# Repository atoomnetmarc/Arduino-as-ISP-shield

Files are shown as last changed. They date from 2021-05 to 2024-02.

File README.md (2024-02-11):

Quickly hacked together Arduino shield to program other Arduino's. Can also be used to program the old AT90S1200 microcontroller using avrdude. I used [AVRDUDESS 2.14](https://github.com/ZakKemble/AVRDUDESS/releases/tag/v2.14
) with avrdude 7.0.

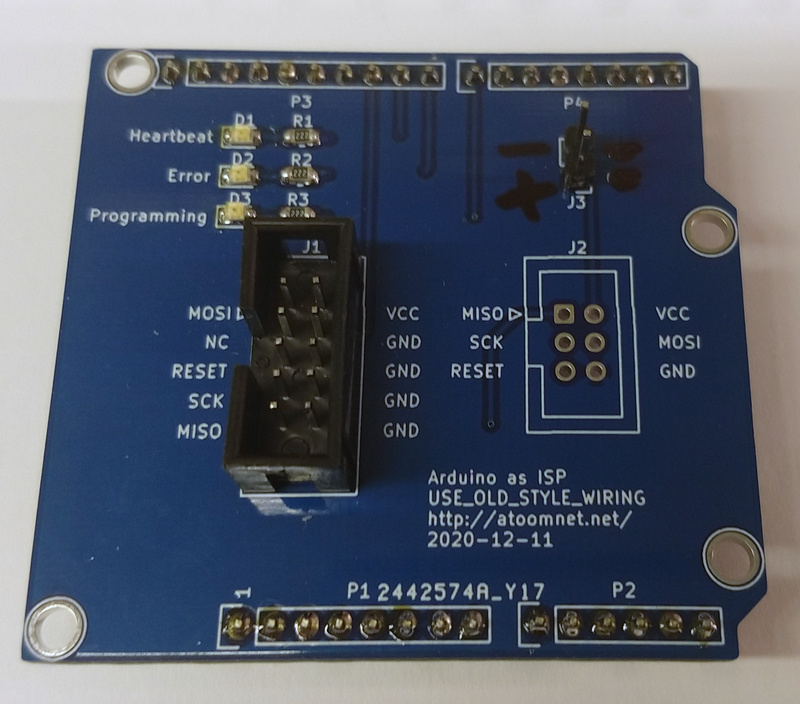
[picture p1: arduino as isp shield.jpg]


Use the [ArduinoISP.ino](https://github.com/rsbohn/ArduinoISP/blob/master/ArduinoISP/ArduinoISP.ino) sketch to program your Arduino.

Use this define:
```#define USE_OLD_STYLE_WIRING```

[![License](https://img.shields.io/badge/License-Apache%202.0-blue.svg)](https://opensource.org/licenses/Apache-2.0)

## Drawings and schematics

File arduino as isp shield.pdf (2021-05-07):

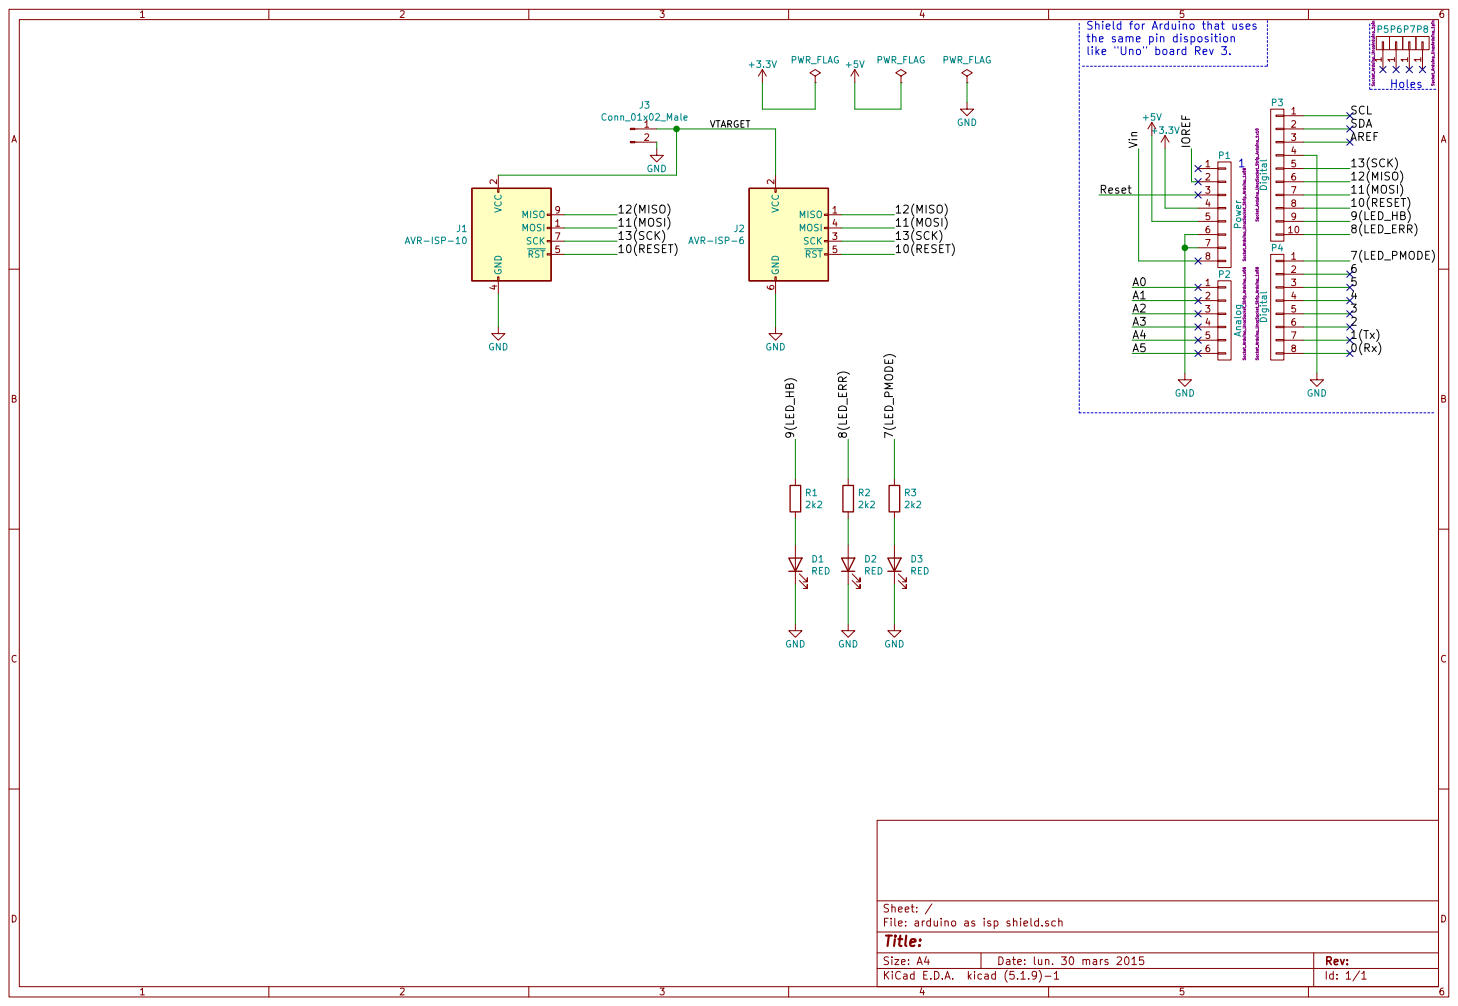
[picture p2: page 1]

the same pin disposition
like "Uno" board Rev 3.

2 SCK 3 MOSI 4 RST 5 GND

File: arduino as isp shield.sch Sheet: /
Id: 1/1 Title:

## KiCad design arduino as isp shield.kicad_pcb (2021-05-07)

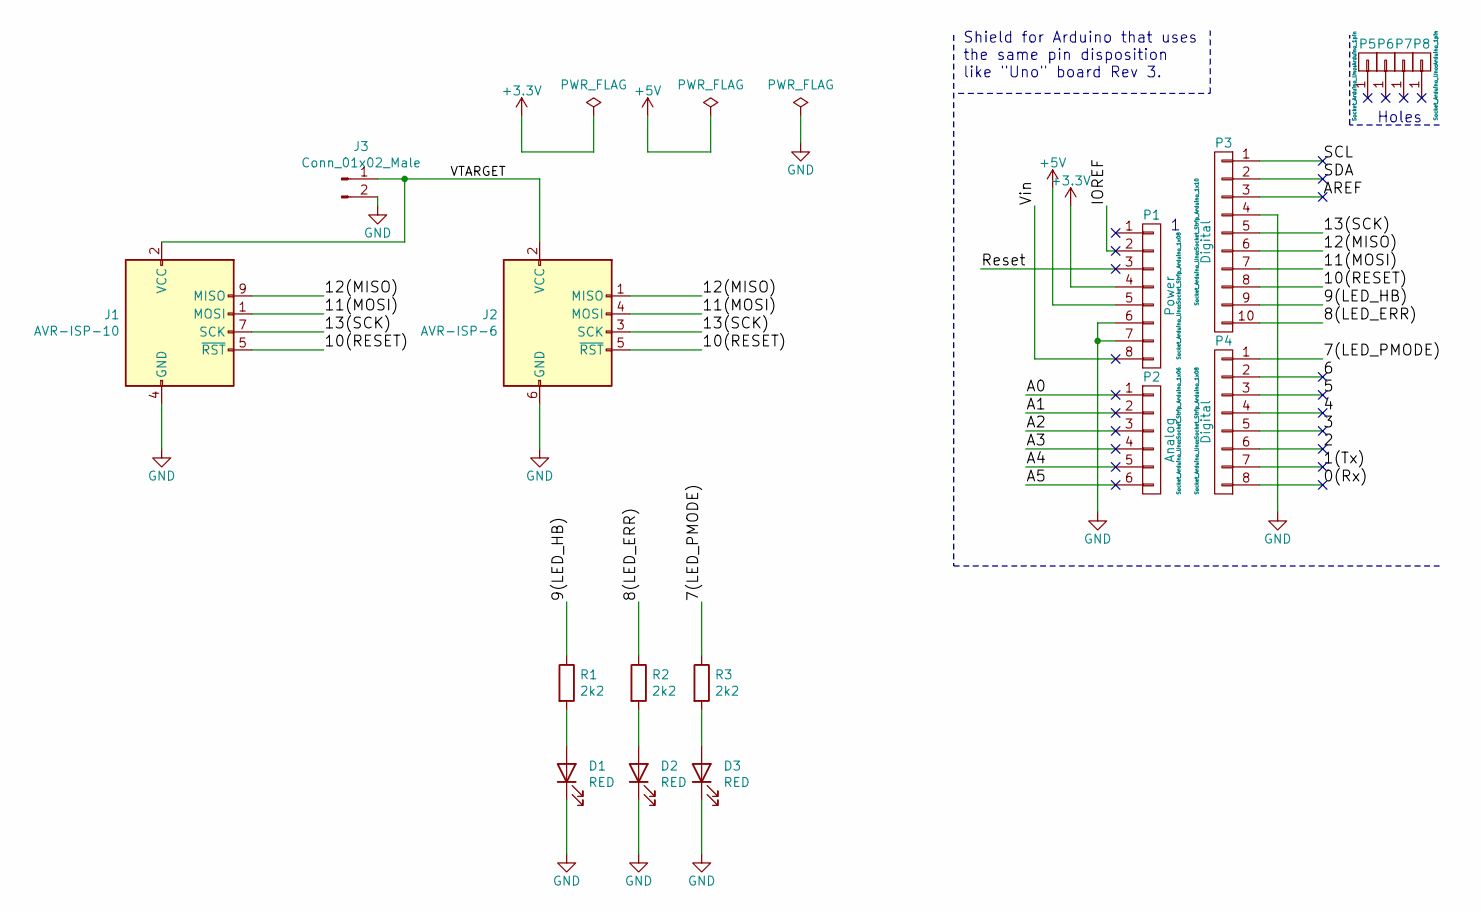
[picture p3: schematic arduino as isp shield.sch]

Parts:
D1, D2, D3: RED; LED_0805_2012Metric_Pad1.15x1.40mm_HandSolder
J1: AVR-ISP-10; IDC-Header_2x05_P2.54mm_Vertical
J2: AVR-ISP-6; IDC-Header_2x03_P2.54mm_Vertical
J3: Conn_01x02_Male; PinHeader_1x02_P2.54mm_Vertical
P1: Power; Socket_Strip_Arduino_1x08
P2: Analog; Socket_Strip_Arduino_1x06
P3: Digital; Socket_Strip_Arduino_1x10
P4: Digital; Socket_Strip_Arduino_1x08
P5, P6, P7, P8: CONN_01X01; Arduino_1pin
R1, R2, R3: 2k2; R_0805_2012Metric_Pad1.20x1.40mm_HandSolder

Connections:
+3V3: P1.4
+5V: P1.5
/0(Rx): P4.8
/1(Tx): P4.7
/2: P4.6
/3: P4.5
/4: P4.4
/5: P4.3
/6: P4.2
/7(LED_PMODE): P4.1, R3.1
/8(LED_ERR): P3.10, R2.1
/9(LED_HB): P3.9, R1.1
/10(RESET): J1.5 (~RST), J2.5 (~RST), P3.8
/11(MOSI): J1.1 (MOSI), J2.4 (MOSI), P3.7
/12(MISO): J1.9 (MISO), J2.1 (MISO), P3.6
/13(SCK): J1.7 (SCK), J2.3 (SCK), P3.5
/A0: P2.1
/A1: P2.2
/A2: P2.3
/A3: P2.4
/A4: P2.5
/A5: P2.6
/AREF: P3.3
/IOREF: P1.2
/Reset: P1.3
/SCL: P3.1
/SDA: P3.2
/VTARGET: J1.2 (VCC), J2.2 (VCC), J3.1
/Vin: P1.8
GND: D1.1 (K), D2.1 (K), D3.1 (K), J1.4 (GND), J1.6 (GND), J1.8 (GND), J1.10 (GND), J2.6 (GND), J3.2, P1.6, P1.7, P3.4
unnamed: D1.2 (A), R1.2
unnamed: D2.2 (A), R2.2
unnamed: D3.2 (A), R3.2

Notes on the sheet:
Holes
Shield for Arduino that uses the same pin disposition like "Uno" board Rev 3.

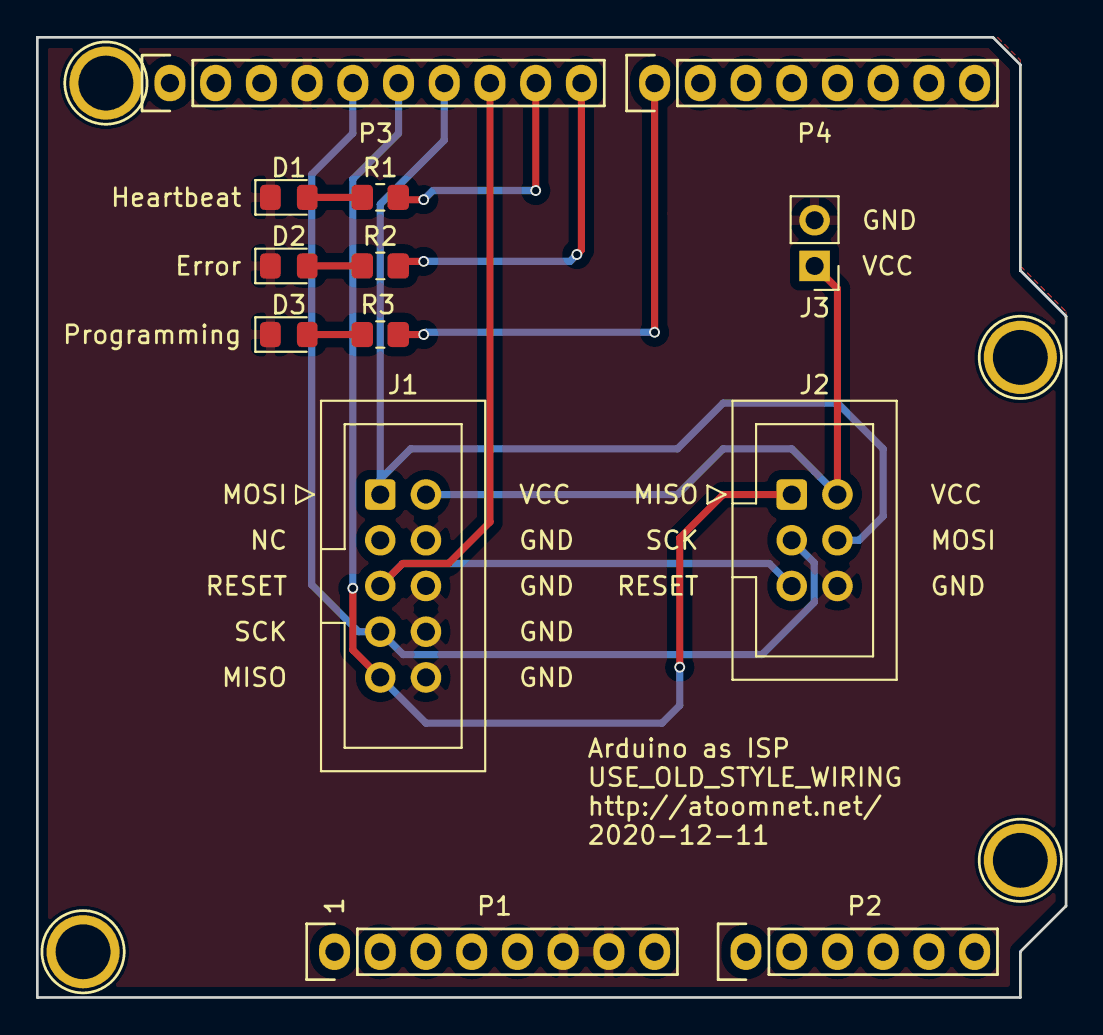
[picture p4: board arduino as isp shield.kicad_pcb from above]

Board: 2 copper layers, 57.1 x 53.3 mm, 17 parts (0 on the bottom side), 12 nets.
